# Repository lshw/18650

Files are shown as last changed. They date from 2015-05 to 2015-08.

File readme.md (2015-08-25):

本项目是一个软硬件设计开源，并且设计软件也是用的开源软件，外壳设计开源，并且外壳设计也是用的开源软件。
并且所有设计文件都是文本格式，这样一个项目。
是一个5口的18650充电测试仪， 可以同时冲5个18650电池，并记录充电电量，并且可以放电测试，并记录测试电量，可以测电池内阻。并且自带时钟，可以显示环境温度的家用电器。

项目的起因，手里有一堆的18650的电池， 需要管理。就设计了一个充电器。功能很简单，就是用线性充电集成电路,用5C的速度给5块18650充电。   
目前完成度80%   

有朋友说需要测试电池容量，于是就给一号充电位置，增加了放电功能和电压检测功能，还增加了2500V隔离串口，sdcard报告导出,lcd显示功能,带了个实时时钟，后续还会增加在线电池管理功能， 方便大家对手头的电池进行编号，对型号，历史数据进行管理。  

sd卡报告功能的初步设想是用静态的一堆css,html5,javascript进行图文曲线输出， 动态数据是同目录下的csv文件。   

串口部分可以用python做跨平台的控制和显示界面。   

scad目录下是openscad做的一些外壳之类的设计   

arduino目录下是充电器的控制程序。   

电路图编辑软件 gEDA  

3d建模 openscad  

软件开发环境 arduino  

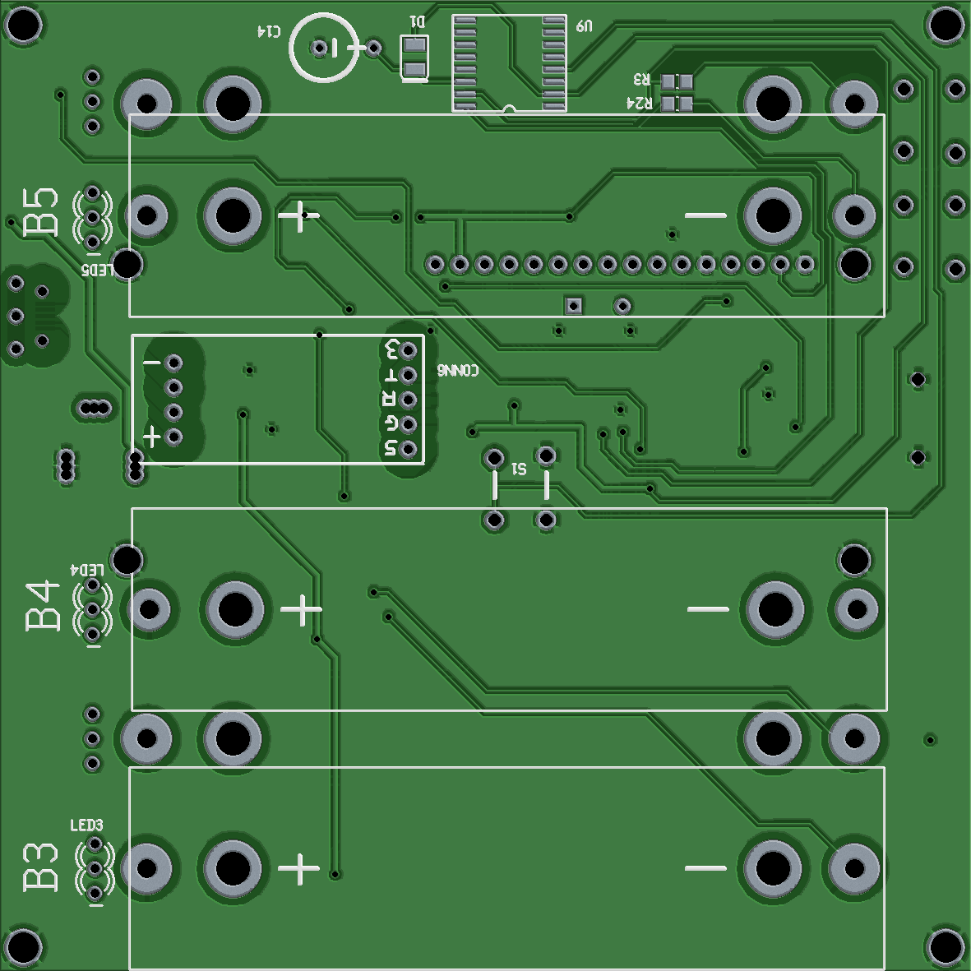
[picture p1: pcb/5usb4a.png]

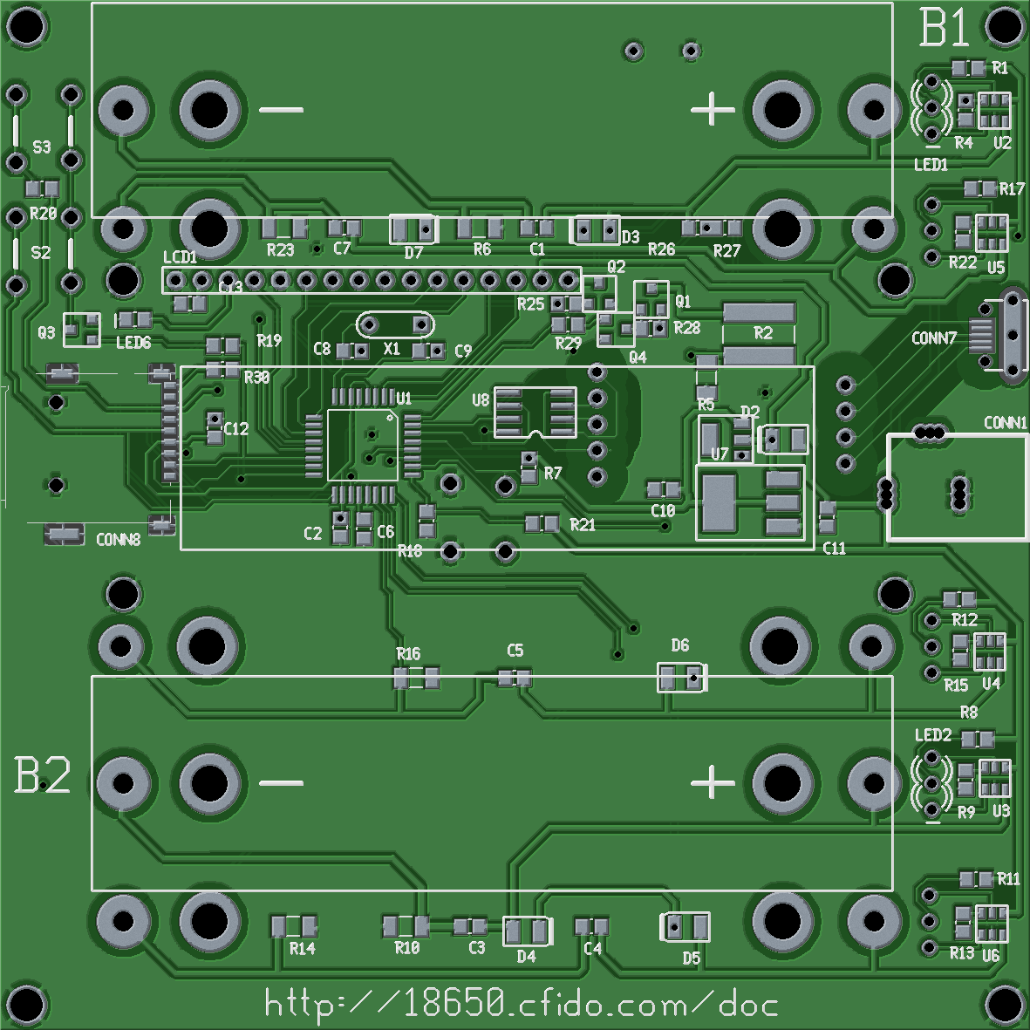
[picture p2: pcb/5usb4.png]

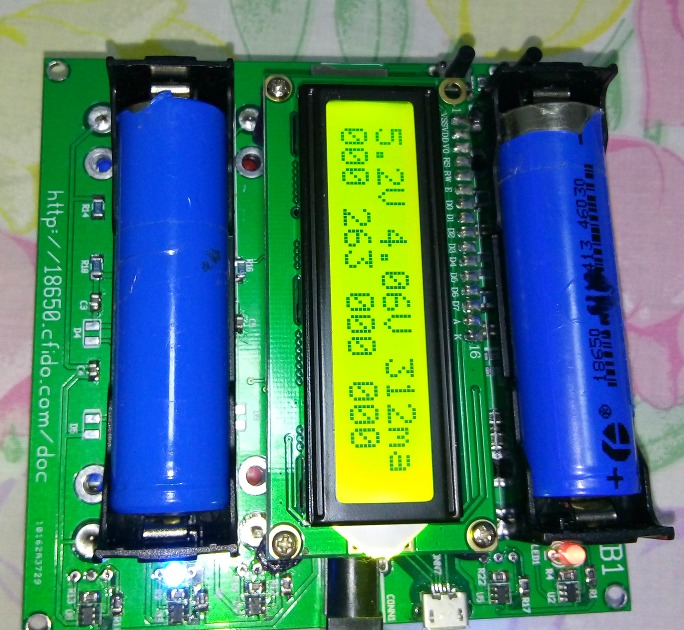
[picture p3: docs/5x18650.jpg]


**ToDo**  
 .html5/css/js程序  
 .python程序  

**Changelog**
2015-07-10 
 .用arduino完成firmware  
 2015-06-05  
 .完成样机制作，充电和状态显示已经可用。  
 2015-05-21  
 .使用现成的电池座，重画电路板，反面3个电池，正面2个电池。  
 2015-05-19  
 .完成样板制作,联调,发现TF座接线错误，飞线修复    
 2015-05-16  
 .接到顺丰速递通知，线路板已经从东莞发来.  
 2015-05-13  
 .通过淘宝下单生产电路板，提交给厂家geber格式即可，第一批内部众筹10个， 连运费共62元/个，6小时完成众酬 ：）  
 2015-05-12  
 .tf卡座封装尺寸调整   
 .重画板子，把尺寸从10X11.5cm缩减到10X10cm,因为10X10cm 加工费用只有40元/10片，而10X11.5cm要110元/10片  

 2015-05-11   
 .调整电阻数值   
 .如果AREF接外部基准电压，就不能用内部的基准电压了，所以adc全部使用内部1.1V基准   

 2015-05-10   
 .VACC需要跟VCC连在一起.   
 .修正mos管的管脚
 .确定A6,A7可以直接在arduino中调用，不需要对arduino打补丁   
 .重新计算adc，选定采样分压，及基准电压   
 .AVCC腿加个电容   
 .放电mos管，加射极随出器进行电平转换.

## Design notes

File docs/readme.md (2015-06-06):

5x18650.jpg  5联18650充电测试仪实物图  
adc.txt   adc设计  
lcd_foot.jpg lcd的支撑脚的3d实物，一次打印25个  
tf.jpg   tfcard卡座  
TP4057.pdf  充电集成电路手册

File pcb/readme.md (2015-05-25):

5usb.sch 电路图  
5usb_sch.png 电路图  

第三版线路板
5usb4.pcb 10X10cm 线路板    
5usb4.png  10X10cm 焊接面  
5usb4a.png  10X10cm 元件面  

第二版线路板
5usb2.pcb 10X10cm 线路板    
5usb2.png  10X10cm 焊接面  
5usb2a.png  10X10cm 元件面  

第一版线路板
5usb.pcb  10X11.5cm 线路板   
5usb.png  10X11.5cm 焊接面  
5usba.png  10X11.5cm 元件面

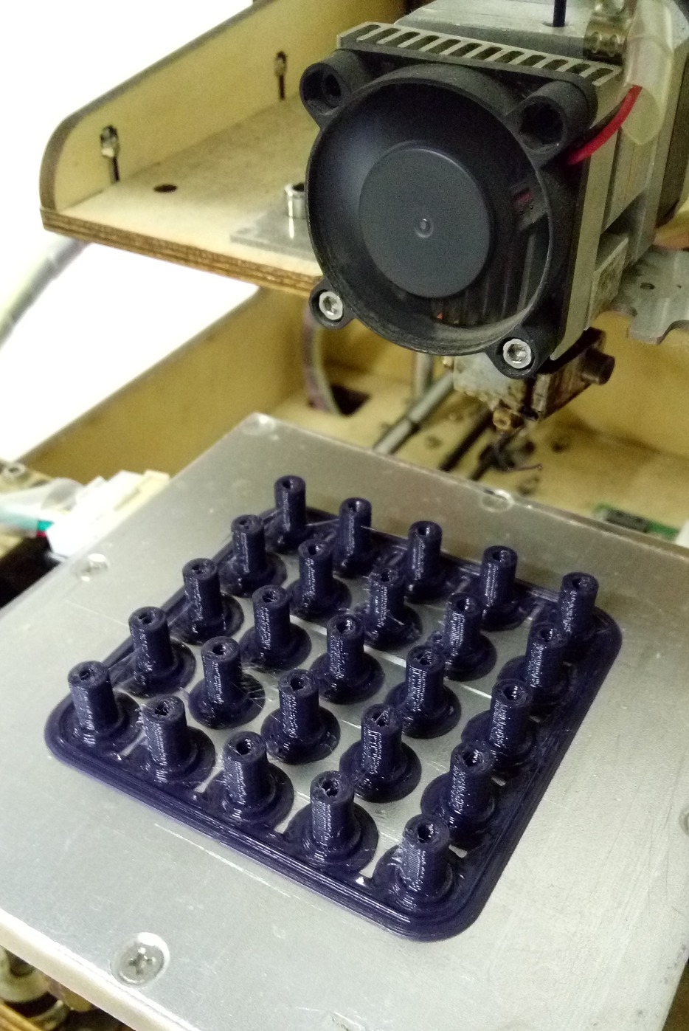
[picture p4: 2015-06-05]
docs/lcd_foot.jpg

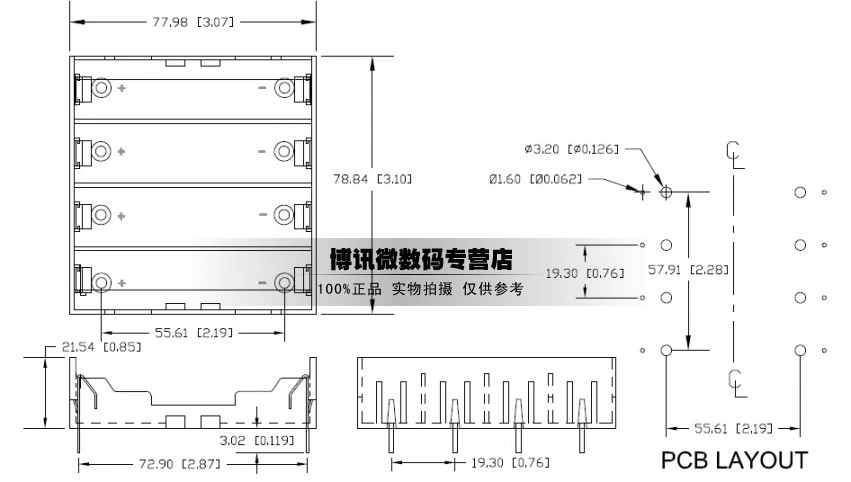
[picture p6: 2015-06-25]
docs/18650x4.webp

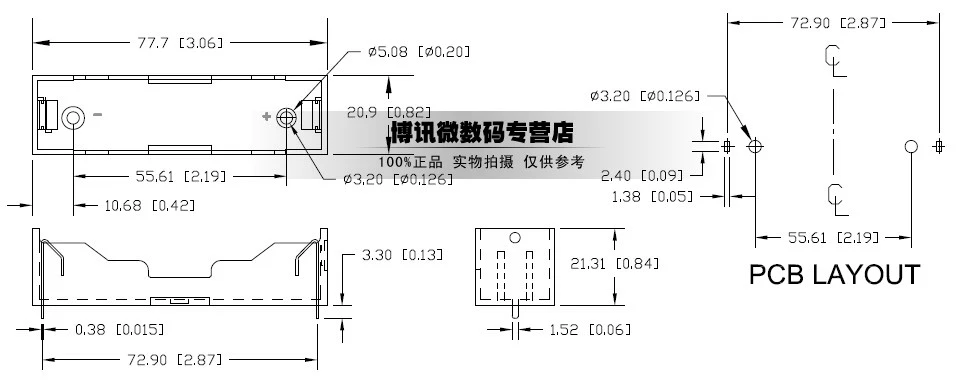
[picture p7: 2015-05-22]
docs/a18650.webp

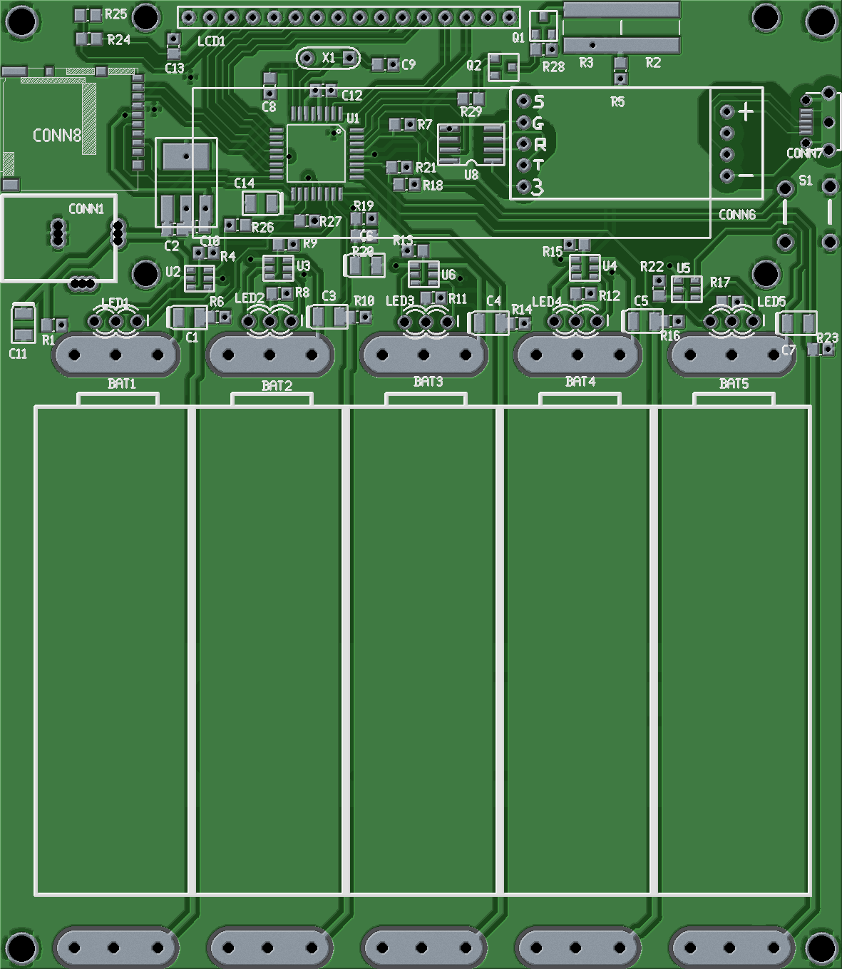
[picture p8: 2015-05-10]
pcb/5usba.png

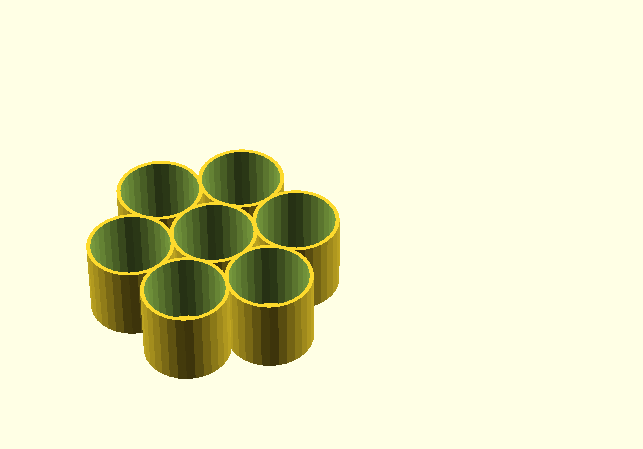
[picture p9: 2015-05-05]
scad/18650x7.png

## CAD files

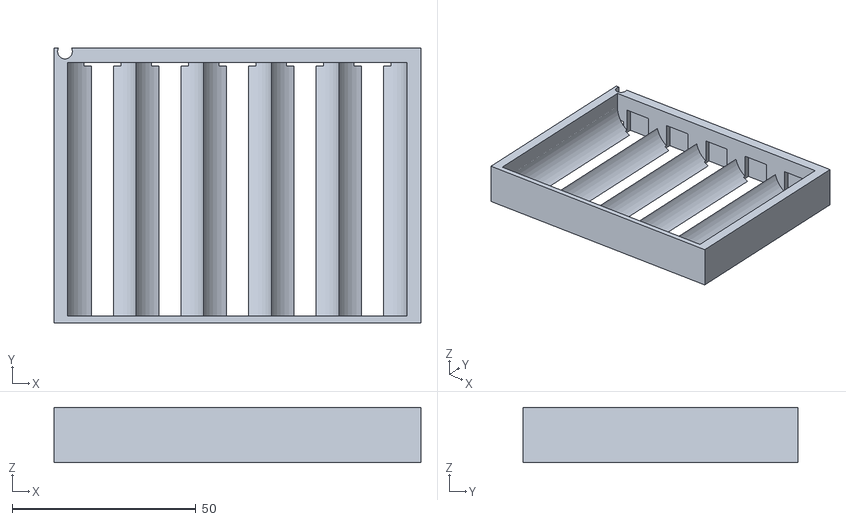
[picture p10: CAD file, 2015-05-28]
scad/5usb.stl
100.0 x 75.0 x 15.0

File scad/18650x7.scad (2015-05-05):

batr=9.75;
bh=1;
$fn=32;
module bat() {
cylinder(h=bh,r=batr+bh);
difference(){
cylinder(h=20,r=batr+bh);
cylinder(h=20,r=batr);
}
}
//bat(); //6

translate([batr+batr+bh,0,0]) bat();
translate([batr*4+bh*2,0,0]) bat();
lx=(batr*2+bh)*cos(60);
ly=(batr*2+bh)*sin(60);
translate([lx,ly,0]) {
bat();
translate([batr*2+bh,0,0]) bat();
translate([(batr*2+bh)*2,0,0]) bat();    //7
translate([lx,ly,0]) {
bat();
translate([batr*2+bh,0,0]) bat();  //7
}
}

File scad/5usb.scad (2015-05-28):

// 第一版线路板的电池座
$fn=40;
x=100;
y=75;
ra=19;
z=ra/2;
xa=92;
xb=xa/5;
x1=(x-xa)/2+xa/5/2;
x2=x1+xa/5;
x3=x2+xa/5;
x4=x3+xa/5;
x5=x4+xa/5;

difference() {
cube([x,y,ra-4]);
translate([x1-z,2,z]) cube([xa+0.5,y-6,z]);
translate([x1,2,z-0.5])    rotate(90, [-1, 0, 0]) cylinder(h=69,r=z);
translate([x2,2,z-0.5])    rotate(90, [-1, 0, 0]) cylinder(h=69,r=z);
translate([x3,2,z-0.5])    rotate(90, [-1, 0, 0]) cylinder(h=69,r=z);
translate([x4,2,z-0.5])    rotate(90, [-1, 0, 0]) cylinder(h=69,r=z);
translate([x5,2,z-0.5])    rotate(90, [-1, 0, 0]) cylinder(h=69,r=z);

translate([x1,y-2-1.5,0])    cube([10,3,z*2],true);
translate([x2,y-2-1.5,0])    cube([10,3,z*2],true);
translate([x3,y-2-1.5,0])    cube([10,3,z*2],true);
translate([x4,y-2-1.5,0])    cube([10,3,z*2],true);
translate([x5,y-2-1.5,0])    cube([10,3,z*2],true);

translate([(x-95)/2,5,0]) {
cylinder(h=z-4,r=1.5);
translate([95,0,0]) cylinder(h=z-4,r=1.5);
}
translate([0,71,0]) {
cube([6.5,y-71,4]);
translate([3,3,0]) cylinder(h=z*2,r=2);
}
}

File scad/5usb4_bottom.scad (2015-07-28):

$fn=20;
pcbx=100;
pcby=100;
bh=2;

translate([bh,bh,0])
translate([2.54,2.54,0]) {
cylinder(h=3.3,r=2); 
 cylinder(h=7,r=1.5);

translate([94.5,94.5,0]){ 
cylinder(h=3.3,r=2); 
 cylinder(h=7,r=1.5);
}
}

difference(){
cube([pcbx+bh+bh,pcby+bh+bh,3]);
translate([bh,bh,0]) {

translate([2.54,2.54,0]) {
translate([95,0,0]) cylinder(h=7,r=2);
translate([0,95,0]) cylinder(h=7,r=2);
}


translate([9,26.5,0]) cube([78,21.3,4]); //B3
translate([9,67.5,0]) cube([78,21.3,4]); //B4
translate([9,0,0]) cube([78,21.3,4]);  //b5
translate([9,50,0]) cube([14,16,4]);   //label 
translate([46,50.5,0]) cube([7,7,4*2],true);  // reset switch  y=50 

translate([90.2,11,0]) cylinder(h=4,r=2);//led3 
translate([90.2,37,0]) cylinder(h=4,r=2);//led4 
translate([90.2,78,0]) cylinder(h=4,r=2);//led5

translate([66+1.5,94.5,0]) cylinder(h=4,r=6.3);//bat 
}
translate([bh,bh,0.3]){
translate([41.5,88,0]) cube([12,12,4]);//U9
}
translate([bh,bh,1]){
translate([1,70,0]) cube([8,23,4]); //s2 s3
translate([55,51.5,0]) cube([32-2,15,4]);  //usbcom 
translate([90.2,11,0]) cylinder(h=4,r=4);//led3
translate([90.2,37,0]) cylinder(h=4,r=4);//led4 
translate([90.2,78,0]) cylinder(h=4,r=4);//led5

translate([11.9,100-76,0])  {
cylinder(h=4,r=2);//B2
translate([73,0,0]) cylinder(h=4,r=2);//B2
}

translate([11.9,100-10.6,0])  {
cylinder(h=4,r=2);//B1
translate([73,0,0]) cylinder(h=4,r=2);//B1
}

translate([90.4,100-76,0]) cylinder(h=4,r=3.5);//led2
translate([90.4,100-10.6,0]) cylinder(h=4,r=3.5);//led1

translate([30,100-9.5,0]) cylinder(h=4,r=4);//r24,r3

translate([58,100-5.8,0]) cylinder(h=4,r=3.5);//d1

translate([86,100-48,0]) cylinder(h=4,r=2.5);//power
translate([93,100-48,0]) cylinder(h=4,r=2.5);//power
translate([90.2,100-42,0]) cylinder(h=4,r=2.5);//power
}
}

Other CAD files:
scad/5usb4_bottom_001.scad
scad/5usb4_bottom_002.scad
scad/5usb4_bottom_007.scad
scad/5usb4_bottom_009.scad
scad/5usb4_top.scad
scad/5usb4_top_001.scad
scad/5usb4_top_002.scad
scad/5usb4_top_003.scad
scad/5usb4_top_007.scad
scad/5usb4_top_009.scad
scad/lcd_foot.scad

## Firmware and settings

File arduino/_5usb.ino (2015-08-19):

/*
https://github.com/lshw/18650
http://18650.cfido.com
  liushiwei@gmail.com qq:10202
   刘世伟 2014-08-08
*/
#define VER "1.6"
//#define HAVE_CALIBRATION 1 //有这个后才会有电压电流校准功能，

//ad管脚定义
// #if defined(__AVR_ATmega328P__)
#define IC1 A4 //Vref R0=0.33 充电1 内置基准电压1.1V 采样电阻0.33欧姆  满量程3.33A分辨率3.255208ma
#define IC2 A1 //Vref R0=0.33 充电2
#define IC3 A0 //Vref R0=0.33 充电3
#define IC4 A7 //Vref R0=0.33 充电4
#define IC5 A5 //Vref R0=0.33 充电5
#define IF1 A3 //Vref R0=0.33 放电1
#define VCC A2 //Vref=1.1  1.1*VCC/1024/24.3*(24.3+499); //外接电源电压
#define V1 A6  //Vref=1.1  1.1*V1/1024/97.6*(97.6+499)  //1号电池电压  

//#define SNSET  11
//EEPROM 地址定义
#define SN_ADDR 10  //10 11 12 13  序列号
#define Wd_al 2 // 2,3,4,5 报警温度
#define Cin_min 6 //6,7,8,9  //温度map()校准参数4个，
#define Cout_min 15 //15 16 17 18
#define Cin_max  19 //19 20 21 22
#define Cout_max 23 //23 24 25 26
#define ADf   27 //27,28,29,30     放电
//#define ADc1  31 //31,32,33,34     充电1
//#define ADc2  35 //35,36,37,38     充电2
//#define ADc3  39 //39,40,41,42     充电3
//#define ADc4  43 //43,44,45,46     充电4
//#define ADc5  47 //47,48,49,50     充电5
#define ADvcc 51 //51,52,53,54     Vcc
#define ADv1  55 //55,56,57,58     v1
//100 ... 164  //mah   

#include <MsTimer2.h>
#include <avr/sleep.h>
//#include<stdlib.h>
#include <LiquidCrystal.h>   //LCD1602a 驱动
LiquidCrystal lcd(8,7,6,5,4,3); //(RS,EN,D4,D5,D6,D7)  lcd接这6条腿
#include <EEPROM.h>
#include <Wire.h>
#include "ds3231.h"
#include <SD.h>  //sdcard 和vfat的库

#define CHARGE 0
#define TOFULL 1 //第一步，先充电到满
#define FULLTOZERO 2 //第二步，然后放电到空 测放电容量
uint32_t sn; //序列号
uint32_t dida=0,dispHoldTime=millis();
int8_t dispse=0;
float wd;   //实际温度值
float wd_al; //报警温度值
float swd;  //芯片读出温度
struct ts t; //时间
float advcc,adv1,adc[6],wdin_min,wdin_max,wdout_min,wdout_max;   //各种校准数值
uint16_t ic[6],vcc,ic5,v1,v1d,r;  //各种测试值   ic[0]放电，ic[1]-ic[5]充电  vcc外部电压  v1 1号电压， v1d 1号关闭重放电的电压
uint16_t sv1d,svcc,sic[6],sv1;   //原始10位ad值
char dispbuff[18];  //显示缓冲区

uint8_t setCount __attribute__ ((section (".noinit"))); //复位计数，记录第几次按动复位键，用于进设置，校准等功能模块
uint8_t proc;   //当前进程
uint32_t b[6] ;  //累计值  b[0]=放电累计  b[1] 充电1累计...  毫安秒

//从eeprom读取一个浮点数
float eeprom_float_read(uint16_t address) {
  float fl;
  uint8_t * fli = (uint8_t *) &fl;
  fli[0]=EEPROM.read(address);
  fli[1]=EEPROM.read(address+1);
  fli[2]=EEPROM.read(address+2);
  fli[3]=EEPROM.read(address+3);
  return fl;
}

//写一个浮点数到eeprom
void eeprom_float_write(uint16_t address,float val) {
  float fl;
  uint8_t * fli = (uint8_t *) &fl;
  if(eeprom_float_read(address)==val) return; //相同就不写
  fl=val;
  EEPROM.write(address,fli[0]);
  EEPROM.write(address+1,fli[1]);
  EEPROM.write(address+2,fli[2]);
  EEPROM.write(address+3,fli[3]);
  return ;
}
void sdSave(char * dataString) {
  //存字符串到sdcard的datalog.csv
  pinMode(10,OUTPUT); //10脚是cs
  File dataFile = SD.open("datalog.csv", FILE_WRITE);
  if(!dataFile) {
    SD.begin(10);
    dataFile = SD.open("datalog.csv", FILE_WRITE);
  }
  if (dataFile) {
    dataFile.println(dataString);
    dataFile.close();
  }
  else {
    Serial.println("sdcard error!");
  }
}
void charge()
{ //电池1充电
  pinMode(9,INPUT);
  digitalWrite(9,LOW); //pin9 高阻
  pinMode(2,OUTPUT);   
  digitalWrite(2,LOW);  //pin2 拉低
}
void Discharge()
{ //电池1放电
  pinMode(9,OUTPUT);
  digitalWrite(9,HIGH);  //pin9 拉高
  pinMode(2,OUTPUT);
  digitalWrite(2,HIGH);   //pin2 拉高
}
void disable()
{ //电池1不充不放
  pinMode(9,OUTPUT);
  digitalWrite(9,HIGH);  //pin9 拉高
  pinMode(2,OUTPUT);
  digitalWrite(2,LOW);   //pin2 拉低
}

uint32_t la;  //15分钟熄灭背光
uint8_t getkey()
{ //获取键盘值，返回  1=a摁下，2=b摁下，3=ab都摁下
  uint8_t ret=0;
  boolean sso,miso,scko;  //保存3个原始状态
  sso=digitalRead(10);   
  miso=digitalRead(12);
  scko=digitalRead(13);

  pinMode(13,INPUT); //sck    sd卡时是输出， 这里改为输入
  digitalWrite(12,HIGH);   //上拉20k电阻
  digitalWrite(13,HIGH);   //上拉20k电阻
  digitalWrite(10,HIGH);   //输出为1,打开Q3
  delay(1);
  ret|=!digitalRead(12);  //采样按键a 
  ret|=!digitalRead(13)<<1; //采样按键b
  pinMode(13,OUTPUT);    //恢复sd卡口线状态
  digitalWrite(10,sso);
  digitalWrite(12,miso);
  digitalWrite(13,scko);
  //if(ret!=0 && la<millis()) {   //有摁键就15分钟内亮背光
   // for(;;) if(!digitalRead(12)==0 && !digitalRead(13)==0) break;
    laon();
  //  dispse=0;
  //  ret=0;
 // }
  return ret;
}

void ad()
{
  float val;  //存放中间结果
  boolean A5V,O11;
  A5V=digitalRead(A5); //保存A5的值
  O11=digitalRead(11);
  pinMode(A5,INPUT);
  digitalWrite(A5,LOW);  
  digitalWrite(A4,LOW);
  digitalWrite(11,LOW);  
  delay(1);
  sic[0]=analogRead(IF1);
  sv1=analogRead(V1);
  sic[1]=analogRead(IC1);  
  if(sic[0]>10 || sic[1]>10){
    disable();
    delay(1); //!
  }
  sic[2]=analogRead(IC2);
  sic[3]=analogRead(IC3);
  sic[4]=analogRead(IC4);
  sic[5]=analogRead(IC5);
  svcc=analogRead(VCC);
  sv1d=analogRead(V1); 
  digitalWrite(11,O11);
  pinMode(A5,OUTPUT);
  if(digitalRead(A5)!=A5V) digitalWrite(A5,A5V);
  oneset();
  val=advcc*svcc;
  vcc=val;  //0.1mv
  val=adv1*sv1;
  v1=val;  //mv
  val=adv1*sv1d;
  v1d=val; //mv
  for(uint8_t i1=0;i1<6;i1++){
    val=adc[i1]*sic[i1];
    ic[i1]=val; //ma
  }
  float x=0;
  if(ic[0]>50) { //放电
    if(sv1<sv1d) {
      x=adv1*(sv1d-sv1)/sic[0]/adc[0]-0.33; //0.33需要校准
      r=x*1000;  
    }  
  } 
  else if(ic[1]>50) {
    if(v1d<v1) {
      x=adv1*(sv1-sv1d)/sic[1]/adc[1]-0.33; //0.33需要校准
      r=x*1000;  
    }
  }
  if(vcc>4000) laon();  //外接电源大于4V ，背光常亮
}
void laon() {
  la=millis()+900000; //背光亮15min  
}
void oneset()
{ //根据当前进程，设置充电/放电状态
  switch(proc) {
  case CHARGE:
  case TOFULL:
    charge();
    break;
  case FULLTOZERO:
    Discharge();
    break;
  }
}
uint8_t bz;
void setwd_al(){ //设置报警温度
  uint8_t key;
  disptime(); //为了取得当前的温度值
  lcd.clear();
  lcd.print("set alert \x03");
  lcd.setCursor(0,1);
  lcd.print(wd_al);
  lcd.print("\x03 alert");
  waitKeyUp();
  setCount--;
  for(;;){
    waitKeyDown();
    key=getkey();
    if(key==1) {
      wd_al += 0.25;
    }
    else if(key==2) {
      wd_al -= 0.25;
    }
    waitKeyUp();
    lcd.setCursor(0,1);
    lcd.print(wd_al);
    eeprom_float_write(Wd_al, wd_al); //写报警温度设置值

  }
}
void setwd(){
  uint8_t key;
  disptime();
  lcd.clear();
  lcd.print("set ");
  lcd.print(swd);
  lcd.print("\x03");
  lcd.setCursor(0,1);
  lcd.print(wd);
  lcd.print("\x03");
  waitKeyUp();
  setCount--;

  if(swd <6.0) {
    lcd.print(" set Low ");  //设低点校准
  }
  else{
    lcd.print(" set High "); //设高点校准 高低点离得越远越好
  }
  for(;;) {
    waitKeyDown(); //等待键按下
    key=getkey();
    if(key==1) {
      wd += 0.25;
    }
    else if(key==2) {
      wd -= 0.25;
    }
    waitKeyUp();  //等待键松开
    lcd.setCursor(0,1);
    lcd.print(wd);
    if(swd<6.0) { //设置低点
      eeprom_float_write(Cin_min, swd);
      eeprom_float_write(Cout_min,wd);
    } 
    else { //设置高点
      eeprom_float_write(Cin_max,swd);
      eeprom_float_write(Cout_max,wd);
    }
  }
}
void setJz1() //放电1校准
{
  lcd.print("Calibration F1");
  waitKeyUp();
  setCount--;
  Discharge();
  ad();
  Discharge();
  Calibration(IF1);
}
void setJz2()
{
  lcd.print("Calibration V1");
  waitKeyUp();
  setCount--;
  disable();
  ad();
  disable();
  Calibration(V1);
}

void setJz() {  //校准充电2-5 ,vcc,v1
  lcd.print("Calibration C1-5");
  waitKeyUp();
  setCount--;
  ad();

  for(;;) {
    if(sic[1]>50) {
      Calibration(IC1);
    }
    else if(sic[2]>50){
      Calibration(IC2);
    }
    else if(sic[3]>50){
      Calibration(IC3);
    }
    else if(sic[4]>50){
      Calibration(IC4);
    }
    else if(sic[5]>50){
      Calibration(IC5);
    }
    else {
      Calibration(VCC);
    }
  }
}
uint16_t a2i(uint8_t offs,uint8_t count) { //count个字节的字符串转换成int16
  uint16_t val=0; 
  for(;count>0;count--) {
    val*=10;
    val+=dispbuff[offs]&0xf;
    offs++;
  }
  return val;
}
uint16_t set_mv(char * name,uint16_t  val) { //修改数字，并返回修改后的数字，
  if(val<3000) val=3000;
  if(val>7000) val=7000;
  sprintf(dispbuff,"%s=%04dmv    ",name, val);
  lcd.print(dispbuff);
  modidisp("hhhh3000hhhhhhhh","hhhh7999hhhhhhhh"); //3000-7999 mv
  val=a2i(4,4);
  return val;
}
uint16_t set_ma(uint8_t offs) {  //修改数字， 并返回修改后的数字
  uint16_t val=ic[offs];
  if(val<100) val=100;
  if(val>700) val=700;
  sprintf(dispbuff,"C%01d=%03dma        ",offs,val);
  if(offs==0) {
    dispbuff[0]='F';
    dispbuff[1]='1';
  }
  lcd.print(dispbuff);
  modidisp("hhh100hhhhhhhhhh","hhh799hhhhhhhhh");   //100-799 ma
  val=a2i(3,3);
  return val;
}
void Calibration(uint8_t adpin) {
  float val;
  uint8_t offs;
  bz=0;
  lcd.setCursor(0,1);
  for(;;){
    offs=0;
    switch(adpin) {
    case VCC:
      vcc=set_mv("Vcc",vcc);
      val=vcc;
      advcc=val/svcc;
      eeprom_float_write(ADvcc,advcc);
      break;
    case V1:
      v1=set_mv("V1 ",v1);
      val=v1;
      adv1=val/sv1;
      eeprom_float_write(ADv1,adv1);
      break;
    case IC5: //offs=5 
      offs++;  
    case IC4: //offs=4
      offs++;
    case IC3: //offs=3
      offs++;
    case IC2: //offs=2
      offs++;
    case IC1: //offs=1
      offs++;
    case IF1: //offs=0

      ic[offs]=set_ma(offs);
      val=ic[offs];
      adc[offs]=val/sic[offs];
      eeprom_float_write(ADf+4*offs,adc[offs]);
      break;
    }
  }
}
void modidisp(char * mins,char * maxs){
  //利用up键和down键，修改dispbuff的内容， mins是最小值列表，maxs是最大值列表， h为不可修改，
  //比如mins="hh100hhhh"，第三位最小为1第四第五位最小为0,其他位不可修改
  uint8_t key; 
  for(uint8_t i1=0;i1<16;i1++){ //跳过不可修改的部分
    if(mins[bz]=='h'){  
      bz++;
      if(bz==16) bz=0;  
    }
    else 
      break;
  }
  lcd.setCursor(bz,1); //设置光标到当前位置，
  lcd.blink();  //让当前位置煽动
  waitKeyDown(); //等待按键
  key=getkey();   //获取按键
  waitKeyUp();  //等待键释放
  lcd.noBlink(); //取消煽动
  if(key==2) { //如果是down键 当前位置加1
    bz++;   
    if(bz==16) bz=0;  //LCD1602只有最多16个字符，每行
  }
  else if(key==1){ //如果按下up键  
    if(dispbuff[bz]<=maxs[bz] && dispbuff[bz] >=mins[bz]) { //不超出范围的话，就加1
      dispbuff[bz]++;
      if(dispbuff[bz]>maxs[bz]) dispbuff[bz]=mins[bz];
    }
  }
  if(dispbuff[bz] < mins[bz]) dispbuff[bz]=mins[bz];
  if(dispbuff[bz] > maxs[bz]) dispbuff[bz]=maxs[bz];

  lcd.setCursor(0, 1);  
  lcd.print(dispbuff); //更新显示
}
void waitKeyUp()
{ //等待键盘松开
  for(;;)  if(!getkey()) break;
}   
void waitKeyDown()
{ //等待键盘按下
  for(;;)  if(getkey()) break;
}   
void setTime(){ //设置实时时钟
  bz=0;
  lcd.print("setTime ");
  lcd.print(setCount);
  waitKeyUp();
  for(;;) {
    lcd.noBlink();
    disptime();
    lcd.setCursor(bz,1);
    lcd.blink();
    modidisp("hh10h00h00h00h00","hh49h19h39h29h59");
    //2015-07-21 00:00   2046-12-31 23:59

    t.sec = 00;
    t.min = a2i(14,2);//(dispbuff[14]&0xf)*10+dispbuff[15]&0xf;//inp2toi(dispbuff, 14);
    t.hour = a2i(11,2);//(dispbuff[11]&0xf)*10+dispbuff[12]&0xf;//inp2toi(dispbuff, 11);
    t.wday=1;
    t.mday = a2i(8,2);//(dispbuff[8]&0xf)*10+dispbuff[9]&0xf;//inp2toi(dispbuff, 8);
    t.mon = a2i(5,2);//inp2toi(dispbuff, 5);
    t.year = 2000 + a2i(2,2);//inp2toi(dispbuff, 2);
    if(t.year>=2048) t.year=2015;
    if(t.mday==0) t.mday=1;
    if(t.mday>31)  t.mday=30;
    if(t.hour>59) t.hour=50;
    if(t.mon>12 || t.mon==0) t.mon=10;
    if(t.mon==2 && t.mday>29) t.mday=20;
    if(t.mon==4 || t.mon==6 || t.mon==9 || t.mon==11) 
      if(t.mday>30) t.mday=30;
    Wire.begin();
    DS3231_init(DS3231_INTCN);
    DS3231_set(t);    
  }
}
void save_eeprom(){
  //存字符串到sdcard的datalog.csv
  lcd.clear();
  lcd.print("EEPROM to file");
  waitKeyUp();
  setCount--;
  pinMode(10,OUTPUT); //10脚是cs
  lcd.setCursor(0,1);
  //sprintf(dispbuff,"eeprom_%d.bin",sn);
  //lcd.print(dispbuff);
  File dataFile = SD.open("eeprom.bin", FILE_WRITE);
  if(!dataFile) {
    SD.begin(10);
    dataFile = SD.open("eeprom.bin", FILE_WRITE);
  }
  if (dataFile) {
    for( uint16_t n=0;n<512;n++) {
      dataFile.write(EEPROM.read(n));
    }
    dataFile.close();
    lcd.setCursor(14,1);
    lcd.print("OK");
  }
  else {
    lcd.setCursor(13,1);
    lcd.print("ERR");
  }
  for(;;) ;
}
boolean i=false;
void calc_sum() { //加当前的测量值到累加值， 被定时器每秒执行一次，b[0]-b[5]是毫安秒
  for(uint8_t i1=0;i1<6;i1++) 
    if(ic[i1]>40) b[i1]+=ic[i1];
}

void setup()
{
  uint8_t upchar[8] = {  /*上箭头*/
    0b00100,
    0b01110,
    0b10101,
    0b00100,
    0b00100,
    0b00100,
    0b00100,
    0b00100
  }
  ,
  downchar[8] = { /*下箭头*/
    0b00100,
    0b00100,
    0b00100,
    0b00100,
    0b00100,
    0b10101,
    0b01110,
    0b00100
  }
  ,
  wdchar[8] = { /*摄氏度*/
    0b10000,
    0b00000,
    0b01110,
    0b10001,
    0b10000,
    0b10000,
    0b10001,
    0b01110
  }
  ,
  oumchar[8] = {  /*欧姆*/
    0b11011,
    0b10101,
    0b10101,
    0b00000,
    0b11111,
    0b10001,
    0b01010,
    0b11011
  }
  ,
  machar[8] = {  /* ma */
    0b11011,
    0b10101,
    0b10101,
    0b10001,
    0b00100,
    0b01010,
    0b01110,
    0b10001
  };

  //载入序列号
  sn=EEPROM.read(SN_ADDR + 3) << 24;
  sn+=EEPROM.read(SN_ADDR + 2) << 16;
  sn+=EEPROM.read(SN_ADDR + 1) << 8;
  sn+=EEPROM.read(SN_ADDR);


  if(EEPROM.read(100)!='2' || EEPROM.read(101)!='0') {
    for(uint8_t i1=2;i1<6*16;i1++) EEPROM.write(100+i1,' ');
    EEPROM.write(100,'2');
    EEPROM.write(101,'0');
    EEPROM.write(102,'1');
    EEPROM.write(103,'5');

    //载入校准值
    eeprom_float_write(Wd_al,34.0);
    eeprom_float_write(Cin_min,0.0);
    eeprom_float_write(Cout_min,0.0);
    eeprom_float_write(Cin_max,30.0);
    eeprom_float_write(Cout_max,30.0);

    for(uint8_t i1=0;i1<6;i1++)
      eeprom_float_write(ADf+i1*4,1.1*1000/0.33/1024); //3.255ma
    eeprom_float_write(ADvcc,1.1*1000*(24.3+499)/24.3/1024);  //23.133278mv 
    eeprom_float_write(ADv1,1.1*1000*(97.6+499)/97.6/1024); //6.56638mv
  }
  uint8_t i1;
  for(i1=0;i1<6;i1++)
    adc[i1]=eeprom_float_read(ADf+4*i1);  //放电ad
  advcc=eeprom_float_read(ADvcc);
  adv1=eeprom_float_read(ADv1);
  wd_al=eeprom_float_read(Wd_al);   //alert 温度
  wdin_min=eeprom_float_read(Cin_min);   //0度时对应的AD值
  wdin_max=eeprom_float_read(Cin_max);     //Cout_max温度对应的 AD值
  wdout_min=eeprom_float_read(Cout_min);       //温度线性校准，一个点在0度， 另一个点取某气温。
  wdout_max=eeprom_float_read(Cout_max);   //某温度
  ACSR &=B10111111; //ACBG=0 模拟比较器禁用
  Serial.begin(9600); //串口9600
  //sdSave("hhhhhh");
  analogReference(INTERNAL); //使用atmega328的内部1.1V 基准源
  analogRead(A0); //第一次转换不准确， 要用掉
  lcd.begin(16, 2); //lcd初始化  16字符2行
  lcd.createChar(2, upchar);   //^
  lcd.createChar(1, downchar); //V
  lcd.createChar(3, wdchar);  //sheshidu
  lcd.createChar(4, oumchar);   //om
  //lcd.createChar(5, machar);  //ma  
  lcd.clear();
  lcd.print("Hello! ");
  if(sn<10) lcd.print("0");
  if(sn<100) lcd.print("0");
  lcd.print(sn);
  lcd.print(" V" VER ); 
  lcd.setCursor(0,1);
  lcd.print("18650.cfido.com");
  pinMode(11,OUTPUT);
  digitalWrite(11,HIGH);
  Wire.begin();
  DS3231_init(DS3231_INTCN);
  DS3231_clear_a1f();
  DS3231_clear_a2f();
  DS3231_set_creg(0x4);
  if(setCount>8) setCount=0; //按住up键，连续复位次数计数
  if(getkey()==1) setCount++; //如果按住上键，计数就加1
  if((DS3231_get_sreg() & 0x80) | getkey()==1) {//如果时间掉电， 直接就进时间设置
    DS3231_set_sreg(0);
    lcd.clear();
    switch(setCount) {
    case 3:
      setwd();
      break;
    case 4:
      setwd_al(); //设置报警温度
      break;
#ifdef HAVE_CALIBRATION  //如果没有定义这个宏，下面的校准程序就没了
    case 5:
      setJz();  //校准充电1-5,Vcc
      break;
    case 6:
      setJz1();  //放电1校准
      break;
    case 7:
      setJz2();  //校准V1
      break;
#endif
    default:
      setTime();
    }
  }
  setCount=0;//清计数
  for(uint8_t i1=0;i1<20;i1++) {
    delay(100); 
    digitalWrite(11,!digitalRead(11)); //lcd背光煽动20次
  }
  Discharge();
  delay(10);
  ad();
  lcd.setCursor(0,0);
  lcd.print("R1=");
  lcd.print(r);
  lcd.print("\x04           ");
  lcd.setCursor(0,1);
  lcd.print("V" VER " " __DATE__);
  for(i1=0;i1<10;i1++) {
    if(getkey()) break;
    delay(200);   //delay 2s or keydown
  }
  laon();
  MsTimer2::set(1000, calc_sum); // 1秒一次调用函数calc_sum进行累加ma时
  MsTimer2::start();
}
uint8_t keya=0;
boolean keydown()
{ //键盘处理，有键按下，会进来
  switch(getkey()) {
  case 1: //按的是up键
    dida=millis();
    waitKeyUp();
    if(proc==CHARGE & (millis()-dida) > 3000){
      //如果按up键的时间超过3秒， 进入测试程序。
      proc=TOFULL;
      return true;
    } 
    //如果按up键短于3秒， 就切换显示历史和当前ma时
    dispse++;
    dispHoldTime=millis()+10000;//显示历史测试mah，会显示10秒  //2mhz /8
    //    dispHistory();//显示dispse对应的值
    break;
  case 2: 
    dida=millis();
    waitKeyUp();
    if(proc!=CHARGE & (millis()-dida) >3000) { //如果按下键多于3秒，就取消测试程序
      proc=CHARGE;
      return true;
    }
    //按down键短于3秒， 反向切换ma时显示
    dispse--;
    dispHoldTime=millis()+10000;   //显示历史测试mah，会显示10秒 2mhz /8
    //    dispHistory();//显示dispse对应的值
    break;
  default:
    return false;
  } 
  if(dispse<0) dispse=5;
  if(dispse>5) dispse=0;
  return true;
}
uint8_t delay60=30; //无背光的情况下，每60秒读取一次时钟，因为读取时钟时背光会瞬间点亮一下。
void disptime()
{
  boolean O11;
  if(delay60>0) delay60--;
  if(la>millis() | delay60==0) {
    delay60=30;
    pinMode(11,OUTPUT);
    O11=digitalRead(11);
    digitalWrite(11,HIGH);
    Wire.begin();
    DS3231_get(&t);
    swd=DS3231_get_treg(); //芯片温度
    digitalWrite(11,O11);
  }
  //map()温度校准
  wd=(swd - wdin_min) * (wdout_max - wdout_min)/(wdin_max - wdin_min) + wdout_min;
  wd=wd*4; //缩小精度
  wd=(int)wd;
  wd=wd/4;
  sprintf(dispbuff,  "%04d-%02d-%02d %02d:%02d",t.year,
  t.mon, t.mday, t.hour, t.min);
  lcd.setCursor(0, 1);  //设置光标位置到第二行的左边
  lcd.print(dispbuff);   //显示时间到第二行
  return;
}

uint16_t eeprom_int16_read(uint16_t addr){ //从eeprom读取一个int16的值
  return((uint16_t)EEPROM.read(addr)+(uint16_t)(EEPROM.read(addr+1)<<8));
}
void eeprom_int16_write(uint16_t addr,uint16_t dat) { //写一个int16到eeprom
  if(eeprom_int16_read(addr)==dat) return;
  EEPROM.write(addr,dat&0xff);
  EEPROM.write(addr+1,(dat>>8)&0xff);
}

//[100]-[109] 2015-07-01 [110]-[113] float mah, [114]-[116] uint16_t ma,
void dispHistory() {
  if(dispHoldTime>millis()) {
    lcd.clear();
    if(dispse==0) 
      lcd.print("F1");
    else{
      lcd.write('C');
      lcd.print(dispse);
    }
    lcd.print(":");
    if(ic[dispse]>0){
      if(dispse==0)
        lcd.print("\x01"); //放电，下箭头
      else
        lcd.print("\x02"); //充电，上箭头
      lcd.print(b[dispse]/3600); //这是把毫安秒换算成毫安时
      lcd.print("mah");
    }
    lcd.setCursor(0,1); 
    //历史测量是字符串方式存放到eeprom中的
    for(uint8_t i1=0;i1<16;i1++) lcd.write(EEPROM.read(100+16*dispse+i1)); //日期 [100] 放电 ， [116] 充1 ，[132] 充2，[148] 充3 .... 

    lcd.setCursor(15,0);
    lcd.print((dispHoldTime-millis())/1000); //当前显示的倒计数， 到0退出History程序 2mhz /8
    return;
  }
  if(ic[0]>10)
    //放电测试状态，显示Vcc,v1,放电电流, 电池内阻
    sprintf(dispbuff,"%01d.%01d %01d.%01d %03d\x01%03d\x04",vcc/1000,(vcc/100)%10,v1/1000,(v1/100)%10,ic[0],r);
  else if(ic[1]>10)
    //充电测试状态 显示vcc,v1,充电电流，温度
    sprintf(dispbuff,"%01d.%01d %01d.%02d %03d %d\x03",vcc/1000,(vcc/100)%10,v1/1000,(v1/10)%100,ic[1],(int)wd);
  else{
    sprintf(dispbuff,"%01d.%01d %01d.%02d      " VER,vcc/1000,(vcc/100)%10,v1/1000,(v1/10)%100);
  }
  if(i==true & proc != 0) {
    dispbuff[0]=proc|0x30;
    dispbuff[1]='/';
    dispbuff[2]='2';
  }
  Serial.println(dispbuff); //把显示buff送串口
  lcd.setCursor(0, 0); //设置光标到第一行第一个字符位置
  lcd.print(dispbuff);  //显示字符串到第一行
  if(ic[0]<=10 && ic[1]<=10) {
    lcd.setCursor(10,0);
    lcd.print(wd);
    lcd.print("\x03");
  }
  //开始准备第二行
  if(i) {
    if( ic[2]!=0 | ic[3]!=0 | ic[4]!=0 | ic[5] != 0 )  {
      sprintf(dispbuff,"%03d %03d %03d %03d ",ic[2],ic[3],ic[4],ic[5]);
      lcd.setCursor(0, 1);  //设置光标位置到第二行的左边
      lcd.print(dispbuff);   //显示buff到第二行
      Serial.println(dispbuff); //输出到串口
    }
    else{
      lcd.setCursor(13,1);
      lcd.print(" ");
    }
    i=false;
  }//第二行准备完毕
  else {
    i=true;
    disptime();
  }
}
boolean have100ma[6]={
  false,false,false,false,false,false};
boolean have0ma[6]={
  false,false,false,false,false,false};
void proc_select() {
  switch(proc) { 
  case TOFULL: //当前第一步，先充到满
    if(ic[1]<10) {  //充满，进入第二步
      have100ma[1]=false;
      proc=FULLTOZERO; 
      b[0]=0;  //放电量累加清零
    }
    break;
  case FULLTOZERO: //当前第二步 放电，
    if(v1<3400) {  //3.4V终止放电电压
      b[1]=0;  //清充电累加
      have0ma[1]=false;
      save(0);//保存放电电量
      proc=CHARGE;
    }
    break;
  }
}
void save(uint8_t sel)
{
  sprintf(dispbuff,"%04d-%02d-%02d %04d",t.year,t.mon,t.mday,b[sel]/3600);
  for(uint8_t i1=0;i1<15;i1++) EEPROM.write(100+sel*16+i1,dispbuff[i1]);
}
void fd() {
  for(uint8_t i1=1;i1<6;i1++) {  //只处理放电 1-5
    if(ic[i1]>100 & ic[i1]<150) have100ma[i1]=true; //经过了100ma这一道，才会在0ma时保存结果， 像电池突然拿下来，再放回去，不影响继续测试
    if(ic[i1]==0) { //结束充电
      have0ma[i1]=true;  //到了0ma
      if(have100ma[i1]==true) {
        save(i1);  //保存结果
        have100ma[i1]=false; //下次不再保存。
      }
    }

    if(ic[i1]>400 & have0ma[i1]==true) { //到过0ma才会是下次测试的开始
      b[i1]=0;
      have0ma[i1]=false;
    }
  }
}
void sleep_ms(uint32_t ms)
{
  unsigned long start ;
  start= millis()+ms;
  set_sleep_mode(SLEEP_MODE_IDLE);
  /*
cli();
   CLKPR =B10000000;
   CLKPR = B00000011;   //调频率16Mhz到2Mhz  则速率延迟都要/8
   sei();
   */
  while (millis() < start){
    sleep_enable();
    sleep_cpu();  //enter sleep mode
    sleep_disable();
  }
  /*
cli();
   CLKPR =B10000000;
   CLKPR = B00000000;   //调频率2Mhz到16Mhz  则速率延迟都要/8
   sei();
   */
}
void loop()
{ //循环

  if(la<millis()) digitalWrite(11,LOW); //背光关闭 15min
  else digitalWrite(11,HIGH);  //背光开

  if(ic[0]<10 & ic[1]<10 & ic[5]<10 & wd>wd_al)// 温度芯片附近不在冲放电，才进行温度报警  
    digitalWrite(11,millis()/100%2);  //背光煽动报警
  if(keydown() && dispHoldTime>millis())
    dispHistory();
  if(dida+1000>millis()) {
    sleep_ms(50);
    return;  //1秒一次执行下面的程序
  }
  Serial.println(CLKPR,HEX);
  dida=millis(); 
  proc_select(); //测试过程处理， 充满电进入第二步，包括写测试值到eeprom
  fd();  //放电过程处理， 写测试值到eeprom
  oneset(); //根据proc选择1号电池的当前任务，充电或者放电
  ad();  //测量
  dispHistory(); //显示dispse对应的值
}

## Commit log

2015-05-04 电路板布局
    [5usb.sch]
2015-05-04 调整布局
    [5usb.sch]
2015-05-05 18650收纳座
    [18650x7.scad]
2015-05-05 线路板初步布线，充电集成电路手册
2015-05-05 拼写错误修正
2015-05-08 布线完成
    [5usb.sch]
2015-05-08 线路板背面
2015-05-09 usb串口增加隔离功能
    [5usb.sch]
2015-05-09 增加背光，lcd1602改3.3V供电
    [5usb.sch]
2015-05-09 导出图片
2015-05-09 过孔变焊盘
2015-05-09 程序初步实现，sd库
    [5usb.sch]
2015-05-09 开pcb目录
    [5usb.sch]
2015-05-10 电池电压采样进行分压，mos管驱动
    [5usb.sch]
2015-05-10 更新图片文件
2015-05-10 增加bom文件
    [5usb.sch]
2015-05-10 敲定adc的采样分压电阻,基准电压
    [5usb.sch]
2015-05-10 adc设计说明
2015-05-10 bom文件
2015-05-10 调整mos的管脚
    [5usb.sch]
2015-05-10 Update readme.md
    VACC需要链接到VCC
2015-05-11 确定电阻值
    [5usb.sch]
2015-05-11 修改电阻值
    [5usb.sch]
2015-05-11 增加几个过孔
2015-05-12 修正tf卡
    [5usb.sch]
2015-05-12 重画板子，把尺寸缩减为10X10cm
    [5usb.sch]
2015-05-12 图片修正
2015-05-12 增加过孔
2015-05-12 调整线与孔的距离
2015-05-16 下单加工线路板
2015-05-18 调整电阻值
    [5usb.sch]
2015-05-18 根据样板调整PCB
2015-05-22 重画线路板
    [5usb.sch]
2015-05-22 增加2个按钮开关
    [5usb.sch]
2015-05-23 调整线路板细节
2015-05-25 增加RealRTC
    [5usb.sch]
2015-05-25 更新adc的对应
2015-05-28 增加实时时钟，背光可控
    [5usb.scad, 5usb.sch, 5usb.stl]
2015-05-28 低功耗3.3V 稳压
2015-05-28 1602a 宽度调整
2015-05-29 6个孔不要接地，因为要焊铆钉，防止铆钉跟电池短路
2015-06-05 lcd的4个支撑脚的3d打印文件
    [lcd_foot.scad]
2015-06-05 初步的firmware， 显示电源电压，电池电压，放电电流,5个充电电流,尚未完成电池内阻测试和充当电容量测试
2015-06-05 实物照片
2015-06-05 给firmware程序增加注释，
2015-06-05 下载程序时板卡选择arduino uno
2015-06-05 加回车符
2015-06-05 实物图片
2015-06-06 修改RealRTC的电源来源
    [5usb.sch]
2015-06-18 增加电池标签,取消老的pcb文件
2015-06-18 初步可用的程序,显示时间,1-5号电池充电电流,1号电池电压，输入电源电压
    [5usb.sch]
2015-06-20 按键测试
2015-06-25 3d外壳的底部，4路18650电池夹尺寸
    [5usb4_bottom.scad]
2015-06-25 3D外壳上盖
    [5usb4_top.scad]
2015-07-01 009,001,007的外壳
    [5usb4_bottom_001.scad, 5usb4_bottom_007.scad, 5usb4_bottom_009.scad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]
2015-07-02 调大一点
    [5usb4_bottom.scad, 5usb4_bottom_001.scad, 5usb4_bottom_007.scad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]
2015-07-03 尺寸微调
    [5usb4_bottom.scad, 5usb4_bottom_001.scad, 5usb4_bottom_007.scad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]
2015-07-09 增加温度显示
2015-07-09 进度修改
2015-07-09 外壳修改
    [5usb4_bottom.scad, 5usb4_top.scad]
2015-07-28 修改外壳
    [5usb4_bottom_001.scad, 5usb4_bottom_002.scad, 5usb4_bottom_003.scad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]
2015-07-28 程序修改
2015-08-02 短按上下键，显示以前测试结果 长按上下键，进入或退出放电测试状态
2015-08-02 6路电流，改成数组存放 显示结果，同时显示历史测试和当前测试 冲放电测试过程处理
2015-08-02 显示当前测试进度,3.6V终止电压判断反了， 第一步测试不做记录，冲到0 就可以进入第二步，
2015-08-02 增加注释
2015-08-03 解决一个死循环问题，缩短程序代码等
2015-08-03 去掉行号调试信息
2015-08-03 增加eeprom初始化程序
2015-08-04 开机测电池内阻
2015-08-04 增加在线网址
2015-08-05 简化测试过程，只做放电测试，充电不在测试过程中进行
2015-08-05 第5版电路图
    [5usb5.sch]
2015-08-05 背光，电池供电防反接，防直充
    [5usb5.sch]
2015-08-06 几个程序bug
2015-08-06 保存校准值到eeprom
2015-08-07 降低功耗到5ma
2015-08-08 v1.6 电池供电情况下，15分钟无操作就关闭背光
2015-08-08 几个bug
2019-02-14 强制github识别为C++,忽略opensacd文件
